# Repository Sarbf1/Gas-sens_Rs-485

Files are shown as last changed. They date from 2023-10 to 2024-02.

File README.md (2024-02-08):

# Gas-sens_Rs-485
a Compact, cheap gas sensor with RS-485 connectivity

## Concept:
24V supplied, Gas detector with half-duplex RS-485 interface. For industrial or home use and application ready product, containing a current or voltage output for reference measurment.
a sinlge LED used for showing cominucation or Error state. The small footprint makes it ready for most plastic enclosures.
the PCB can be hand-solderd with a bit of skill. 
Use cases can be in Garage systems (linked with the vents and gas alarm system), hobbyist workshop or any other room such as Office spaces and schools.

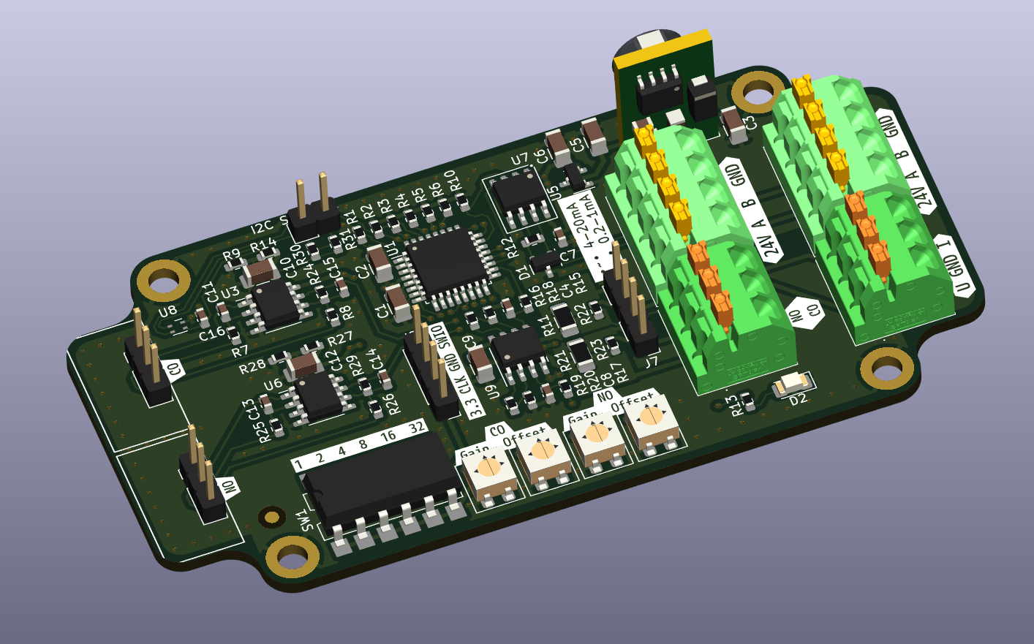
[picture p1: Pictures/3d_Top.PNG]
front-view

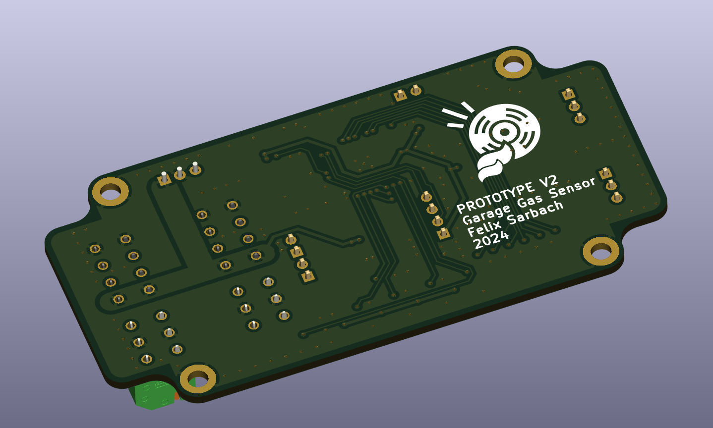
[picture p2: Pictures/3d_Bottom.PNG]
back-view


## Components

A STM32G031K8 is the logical unit. Is is cheap and readily available.
The very most components use standart fooprints. Thus, they are easily exchangeble in case of a shortage.
All parts are SMD, except for the Sensors, DCDC converter and Connectors.
All PCB components can be sourced by Mouser, except for the Gas Sensor.
For developement purposes (TAG v0.1) a gas sensor type MQ-X were used (MQ-7 and MQ-135)
TAG v0.2 makes use of the nemoto sensor, that uses low current and is more gas specific. 
The I2C conection gives a possibility, to further extend with more sensors, such as the Sensirion SHT4X.

## Programming
Hardware is developed in KiCad 7.0.

everything is programmed on STM Cube IDE. The Sensor and trim potentiometers are read-in using DMA.
The max and minimum values of the potentiometers can be set by the Modbus. the specific address are found in the excel-table "Modbus-memorymap" in the software folder.

## Simulation
Low pass filter for the PWM (from uC to OpAmp to voltag eand current output) has been simulated using LTSpice.

## next steps
- [X] PWM filter simulations
- [x] build and test prototype
- [x] Prgram IC for analog measurment and analog output
- [x] Find better sensor supplier and include it on second version PCB -> nemoto sensors
- [x] implement Modbus via RS-485
- [ ] create Bill of material
- [x] Make second physical prototype

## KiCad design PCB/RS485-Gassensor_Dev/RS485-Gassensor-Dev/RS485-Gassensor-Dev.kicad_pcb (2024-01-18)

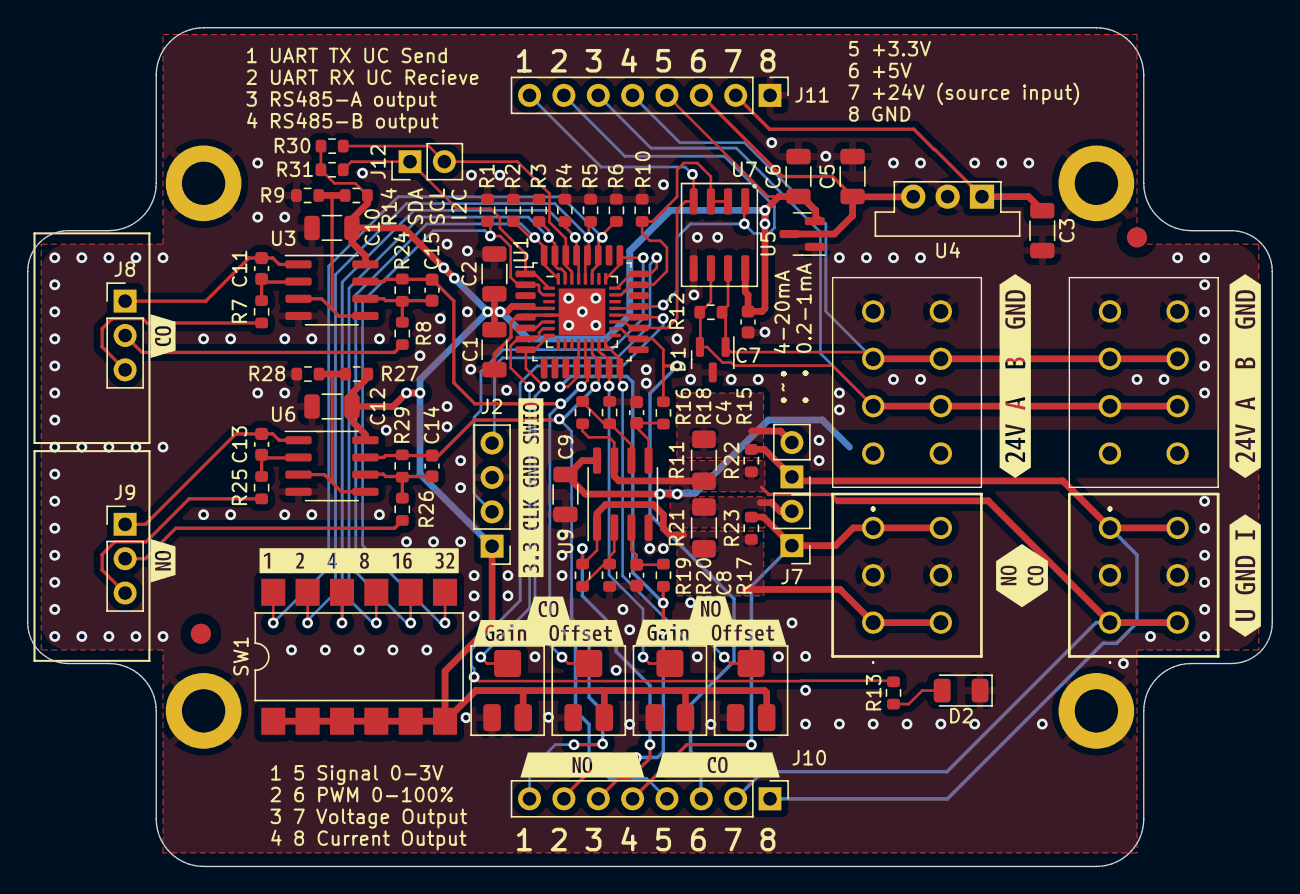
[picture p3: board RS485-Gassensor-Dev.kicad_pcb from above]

Board: 2 copper layers, 92.0 x 62.0 mm, 93 parts (0 on the bottom side), 52 nets.

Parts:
C1: CAP4.7uF; C_1206_3216Metric
C2: CAP100nF; C_1206_3216Metric
C3: CAP10uF; C_1206_3216Metric
C4, C8: 470nF; C_0603_1608Metric
C5: CAP22uF; C_1206_3216Metric
C6, C9, C10, C12: CAP1uF; C_1206_3216Metric
C7: CAP100nF; C_0603_1608Metric
C11, C13, C14, C15: CAP1uF; C_0603_1608Metric
D1: SM712_SOT23; SOT-23
D2: IR26-21C_L110_TR8; LED_1206_3216Metric
FID1, FID2: Fiducial; Fiducial_1.5mm_Mask3mm
H1, H2, H3, H4: MountingHole_Pad; MountingHole_3.2mm_M3_DIN965_Pad
J1, J3: Screw_Terminal_01x08; 1862068
J2: Screw_Terminal_01x04; PinHeader_1x04_P2.54mm_Vertical
J4, J5: Screw_Terminal_01x06; 1071000
J6, J7, J12: Conn_01x02_Pin; PinHeader_1x02_P2.54mm_Vertical
J8, J9: Conn_01x03; PinHeader_1x03_P2.54mm_Vertical
J10, J11: Conn_01x08; PinHeader_1x08_P2.54mm_Vertical
R1, R2, R3, R4, R5, R6, R7, R10, R24, R25, R29: R10K; R_0603_1608Metric
R8, R26: 10; R_0603_1608Metric
R9, R15, R17, R27, R28: 1k; R_0603_1608Metric
R11, R21: R470; R_1206_3216Metric_Pad1.30x1.75mm_HandSolder
R12: R220; R_0603_1608Metric
R13: R100; R_0603_1608Metric
R14, R16, R19: 2.2k; R_0603_1608Metric
R18, R20, R30, R31: R1K; R_0603_1608Metric
R22, R23: 10KR; R_0603_1608Metric
RV1, RV2, RV3, RV4: R_Poti_1K; Potentiometer_Bourns_3214J_Horizontal
SW1: SW_DIP_x06; SMDIP-12_W9.53mm
U1: STM32G031K8Tx; LQFP-32_7x7mm_P0.8mm
U2: STM32G031K8Ux; QFN-32-1EP_5x5mm_P0.5mm_EP3.45x3.45mm
U3, U6: MCP6002-xMS; SOIC-8_3.9x4.9mm_P1.27mm
U4: OKI-78SR-5_1.5-W36-C; Converter_DCDC_Murata_OKI-78SR_Vertical
U5: AP2127N-3.3; SOT-23
U7: LT1785xS8; SOIC-8_3.9x4.9mm_P1.27mm
U9: AD8676; SOIC-8_3.9x4.9mm_P1.27mm
kibuzzard-64E925B6: G***; kibuzzard-64E925B6
kibuzzard-64E958EB: G***; kibuzzard-64E958EB
kibuzzard-64E958FD: G***; kibuzzard-64E958FD
kibuzzard-64E92756: G***; kibuzzard-64E92756
kibuzzard-64ECCA5B: G***; kibuzzard-64ECCA5B
kibuzzard-64ECCA80: G***; kibuzzard-64ECCA80
kibuzzard-64ECCBAE: G***; kibuzzard-64ECCBAE
kibuzzard-651DD8EE: G***; kibuzzard-651DD8EE
kibuzzard-651DD908: G***; kibuzzard-651DD908
kibuzzard-655D1F2B: G***; kibuzzard-655D1F2B
kibuzzard-655D1F21: G***; kibuzzard-655D1F21
kibuzzard-650224BF: G***; kibuzzard-650224BF
kibuzzard-650224CC: G***; kibuzzard-650224CC
kibuzzard-650224F1: G***; kibuzzard-650224F1

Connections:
+3.3V: C1.1, C2.1, C6.1, C7.1, C10.1, C12.1, J2.1, J11.4, R14.2, R27.2, R30.1, R31.1, RV1.1, RV2.1, RV3.1, RV4.1, SW1.1, SW1.2, SW1.3, SW1.4, SW1.5, SW1.6, U1.4 (VDD), U2.4 (VDD), U3.8 (V+), U5.2 (VO), U6.8 (V+), U7.8 (VCC)
+5V: C5.1, J11.3, U4.3 (OUT), U5.3 (VI)
+24V: C3.1, C9.1, J1.1, J1.2, J3.1, J3.2, J11.2, U4.1 (IN), U9.8 (V+)
/Inputs and sensors/Counter_CO: C11.1, J8.1, U3.1
/Inputs and sensors/Counter_NO: C13.1, J9.1, U6.1
/Inputs and sensors/Reference_CO: J8.3, R7.1
/Inputs and sensors/Reference_NO: J9.3, R25.1
/Inputs and sensors/Working_CO: J8.2, R8.1
/Inputs and sensors/Working_NO: J9.2, R26.1
CO: C15.2, J10.4, R24.2, U1.13 (PA6), U2.13 (PA6), U3.7
DIP0: R1.1, SW1.7, U1.2 (PC14), U2.2 (PC14)
DIP1: R2.1, SW1.8, U1.32 (PB8), U2.32 (PB8)
DIP2: R3.1, SW1.9, U1.31 (PB7), U2.31 (PB7)
DIP3: R4.1, SW1.10, U1.29 (PB5), U2.29 (PB5)
DIP4: R5.1, SW1.11, U1.28 (PB4), U2.28 (PB4)
DIP5: R6.1, SW1.12, U1.27 (PB3), U2.27 (PB3)
GND: C1.2, C2.2, C3.2, C4.2, C5.2, C6.2, C7.2, C8.2, C9.2, C10.2, C12.2, D1.3 (common), D2.1 (K), H1.1, H2.1, H3.1, H4.1, J1.7, J1.8, J2.3, J3.7, J3.8, J4.3, J4.4, J5.3, J5.4, J11.1, R1.2, R2.2, R3.2, R4.2, R5.2, R6.2, R9.1, R10.2, R18.2, R20.2, R28.1, RV1.3, RV2.3, RV3.3, RV4.3, U1.5 (VSS), U2.5 (VSS), U2.33 (VSS), U3.4 (V-), U4.2 (GND), U5.1 (GND), U6.4 (V-), U7.5 (GND), U9.4 (V-)
Gain_CO: RV1.2, U1.7 (PA0), U2.7 (PA0)
Gain_NO: RV3.2, U1.15 (PB0), U2.15 (PB0)
I2C_SCL: J12.2, R30.2, U1.30 (PB6), U2.30 (PB6)
I2C_SDA: J12.1, R31.2, U1.1 (PB9), U2.1 (PB9)
I_Out_CO: J5.5, J5.6, J6.1, J10.1, R22.2
I_Out_NO: J4.5, J4.6, J7.1, J10.5, R23.2
LED: R13.2, U1.20 (PC6), U2.20 (PC6)
NO2: C14.2, J10.8, R29.2, U1.14 (PA7), U2.14 (PA7), U6.7
unnamed: D2.2 (A), R13.1
unnamed: J6.2, R11.2
unnamed: J7.2, R21.2
unnamed: R9.2, R14.1, U3.3 (+), U3.5 (+)
unnamed: C11.2, R7.2, U3.2 (-)
unnamed: C15.1, R8.2, R24.1, U3.6 (-)
unnamed: R27.1, R28.2, U6.3 (+), U6.5 (+)
unnamed: C13.2, R25.2, U6.2 (-)
unnamed: C14.1, R26.2, R29.1, U6.6 (-)
unnamed: C8.1, R17.2, U9.3 (+)
unnamed: R19.2, R20.1, U9.2 (-)
unnamed: C4.1, R15.2, U9.5 (+)
unnamed: R16.2, R18.1, U9.6 (-)
RS485-A: D1.2 (A2), J1.3, J1.4, J3.3, J3.4, J11.6, R12.1, U7.6 (A)
RS485-B: D1.1 (A1), J1.5, J1.6, J3.5, J3.6, J11.5, R12.2, U7.7 (B)
Read_!Enable: R10.1, U1.23 (PA12/PA10), U2.23 (PA12/PA10), U7.2 (~RE), U7.3 (DE)
SWCLK: J2.2, U1.25 (PA14), U2.25 (PA14)
SWDIO: J2.4, U1.24 (PA13), U2.24 (PA13)
T_NRST-Button: U1.6 (PF2), U2.6 (PF2)
UART_RX: J11.7, U1.21 (PA10/NC), U2.21 (PA10/NC), U7.1 (RO)
UART_TX: J11.8, U1.19 (PA9/NC), U2.19 (PA9/NC), U7.4 (DI)
U_Out_CO: J5.1, J5.2, J10.2, R11.1, R16.1, R22.1, U9.7
U_Out_NO: J4.1, J4.2, J10.6, R19.1, R21.1, R23.1, U9.1
analog_PWM_CO: J10.3, R15.1, U1.18 (PA8), U2.18 (PA8)
analog_PWM_NO: J10.7, R17.1, U1.12 (PA5), U2.12 (PA5)
offset_CO: RV2.2, U1.8 (PA1), U2.8 (PA1)
offset_NO: RV4.2, U1.16 (PB1), U2.16 (PB1)

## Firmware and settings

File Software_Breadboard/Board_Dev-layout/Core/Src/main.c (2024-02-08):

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
/* Includes ------------------------------------------------------------------*/
#include "main.h"
#include "adc.h"
#include "dma.h"
#include "i2c.h"
#include "tim.h"
#include "usart.h"
#include "gpio.h"

/* USER CODE BEGIN Includes */
#include <stdio.h>
#include <stdbool.h>
#include "modbusSlave.h"

/* USER CODE END Includes */


/* USER CODE BEGIN PV */

//UART_HandleTypeDef huart1;

struct sensor {
	uint32_t *input;
	uint32_t *gain;
	uint32_t *offset;
	uint32_t output;
};

uint8_t SLAVEID = 0;

/* USER CODE END PV */

void SystemClock_Config(void);
/* USER CODE BEGIN PFP */

//static void MX_GPIO_Init(void);
//static void MX_USART1_UART_Init(void);


/* USER CODE END PFP */

/* USER CODE BEGIN 0 */

uint32_t value_adc_DMA[7]={0,0,0,0,0,0,0};  // #TODO restructure as struct instrad array
int32_t y = 0;
int32_t a = 1;
int32_t x = 1;
int32_t b = 0;

uint8_t RxData[256];
uint8_t TxData[256];


void HAL_UARTEx_RxEventCallback(UART_HandleTypeDef *huart, uint16_t Size)
{
	if (RxData[0] == SLAVEID)
	{
		switch (RxData[1]){
		case 0x03:
			readHoldingRegs();
			break;
		case 0x04:
			readInputRegs();
			break;
		case 0x01:
			readCoils();
			break;
		case 0x02:
			readInputs();
			break;
		case 0x06:
			writeSingleReg();
			break;
		case 0x10:
			writeHoldingRegs();
			break;
		case 0x05:
			writeSingleCoil();
			break;
		case 0x0F:
			writeMultiCoils();
			break;
		default:
			modbusException(ILLEGAL_FUNCTION);
			break;
		}
	}

	HAL_UARTEx_ReceiveToIdle_IT(&huart1, RxData, 256);
}



/* USER CODE END 0 */

/**
  * @brief  The application entry point.
  * @retval int
  */
int main(void)
{
  /* MCU Configuration--------------------------------------------------------*/

  /* Reset of all peripherals, Initializes the Flash interface and the Systick. */
  HAL_Init();

  /* Configure the system clock */
  SystemClock_Config();

  /* Initialize all configured peripherals */
  MX_GPIO_Init();
  MX_DMA_Init();
  MX_ADC1_Init();
  MX_TIM1_Init();
  MX_USART1_UART_Init();
  MX_TIM2_Init();
  MX_I2C1_Init();
  /* USER CODE BEGIN 2 */


	char port0 = HAL_GPIO_ReadPin(GPIO_IN_DIP0_GPIO_Port, GPIO_IN_DIP0_Pin);
	char port1 = HAL_GPIO_ReadPin(GPIO_IN_DIP1_GPIO_Port, GPIO_IN_DIP1_Pin);
	char port2 = HAL_GPIO_ReadPin(GPIO_IN_DIP2_GPIO_Port, GPIO_IN_DIP2_Pin);
	char port3 = HAL_GPIO_ReadPin(GPIO_IN_DIP3_GPIO_Port, GPIO_IN_DIP3_Pin);
	char port4 = HAL_GPIO_ReadPin(GPIO_IN_DIP4_GPIO_Port, GPIO_IN_DIP4_Pin);
	char port5 = HAL_GPIO_ReadPin(GPIO_IN_DIP5_GPIO_Port, GPIO_IN_DIP5_Pin);

	SLAVEID = (port0 << 5) | (port1 << 4) | (port2 << 3) | (port3 << 2) | (port4 << 1) |  port5 ;

  HAL_UARTEx_ReceiveToIdle_IT(&huart1, RxData, 256);

	struct sensor Co, No, Temp;

	Co.input = &value_adc_DMA[0];
	No.input = &value_adc_DMA[1];
	Co.gain = &value_adc_DMA[2];
	Co.offset = &value_adc_DMA[3];
	No.gain = &value_adc_DMA[4];
	No.offset = &value_adc_DMA[5];
	Temp.input = &value_adc_DMA[6];
	Temp.gain = 1; //#TODO get this value from internal saved reference value
	Temp.offset = 0;



	HAL_TIM_PWM_Start(&htim1, TIM_CHANNEL_1); //start output PWM 1 CO
	HAL_TIM_PWM_Start(&htim2, TIM_CHANNEL_1); //start output PWM 2 NO
	TIM1->CCR1 =1;
	TIM1->CCR2 =1;
	HAL_ADC_Start_DMA(&hadc1, value_adc_DMA, 7); //aquire date from all ADC

  /* USER CODE END 2 */

  /* Infinite loop */
  /* USER CODE BEGIN WHILE */
	while (1)
	{
    /* USER CODE END WHILE */

    /* USER CODE BEGIN 3 */

		HAL_ADC_Start_DMA(&hadc1, value_adc_DMA, 7); //this step takes ca 50uS #TODO perhaps export to internal timer callback (trigger)


		x= TIM1->ARR* *Co.input/4095;
		a= *Co.gain*(Input_Registers_Database[13]-Input_Registers_Database[11])/4095+Input_Registers_Database[11]; // initial pitch between 20 and 180 [in percent]
		b= *Co.offset*(Input_Registers_Database[16]-Input_Registers_Database[14])/4095 + Input_Registers_Database[14]; //results between -409 and +409
		y=a*x*0.01+b*0.1;
		if (y<0) {y=0;}
		if (y>TIM1->ARR) {y=TIM1->ARR;}

		TIM1->CCR1 =y ;

		x= (TIM2->ARR* *No.input)/4095;
		a= *No.gain*(Input_Registers_Database[23]-Input_Registers_Database[21])/4095+Input_Registers_Database[21];
		b= *No.offset*(Input_Registers_Database[26]-Input_Registers_Database[24])/4095 + Input_Registers_Database[24];
		y=a*x*0.01+b*0.1;
		if (y<0) {y=0;}
		if (y>TIM2->ARR) {y=TIM2->ARR;}

		TIM2->CCR1 = y;


		Input_Registers_Database[10]=*Co.input;
		Input_Registers_Database[12]=*Co.gain;
		Input_Registers_Database[15]=*Co.offset;
		Input_Registers_Database[17]=TIM1->CCR1;

		Input_Registers_Database[20]=*Co.input;
		Input_Registers_Database[22]=*Co.gain;
		Input_Registers_Database[25]=*Co.offset;
		Input_Registers_Database[27]=TIM2->CCR1;

		//Input_Registers_Database[37]=Temp;

		HAL_GPIO_TogglePin(GPIOC, GPIO_PIN_6); //toggle LED to measure cycle time
	}
  /* USER CODE END 3 */
}

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


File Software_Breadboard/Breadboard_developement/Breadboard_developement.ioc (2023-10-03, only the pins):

Mcu.UserName=STM32G031K8Tx
PA0.GPIO_Label=ADC1_IN0_GAIN_CO
PA0.Signal=ADC1_IN0
PA1.GPIO_Label=ADC1_IN1_OFFSET_CO
PA1.Signal=ADC1_IN1
PA10.Signal=USART1_RX
PA13.GPIO_Label=T_JTMS
PA13.Signal=SYS_SWDIO
PA14-BOOT0.GPIO_Label=T_JTCK
PA14-BOOT0.Signal=SYS_SWCLK
PA2.GPIO_Label=T_VCP_TX
PA2.Signal=USART2_TX
PA3.GPIO_Label=T_VCP_RX
PA3.Signal=USART2_RX
PA5.GPIO_Label=TIM2_CH1_PWM_NO
PA5.Signal=S_TIM2_CH1_ETR
PA6.GPIO_Label=ADC1_IN6_CO
PA6.Signal=ADC1_IN6
PA7.GPIO_Label=ADC1_IN7_NO
PA7.Signal=ADC1_IN7
PA8.GPIO_Label=TIM1_CH1_PWM_CO
PA8.Signal=S_TIM1_CH1
PA9.Signal=USART1_TX
PB0.GPIO_Label=ADC1_IN8_GAIN_NO
PB0.Signal=ADC1_IN8
PB1.GPIO_Label=ADC1_IN9_OFFSET_NO
PB1.Signal=ADC1_IN9
PB3.GPIO_Label=GPIO_IN_DIP5
PB3.Signal=GPIO_Input
PB4.GPIO_Label=GPIO_IN_DIP4
PB4.Signal=GPIO_Input
PB5.GPIO_Label=GPIO_IN_DIP3
PB5.Signal=GPIO_Input
PB6.GPIO_Label=GPIO_IN_DIP2
PB6.Signal=GPIO_Input
PB7.GPIO_Label=GPIO_IN_DIP1
PB7.Signal=GPIO_Input
PB8.GPIO_Label=GPIO_IN_DIP0
PB8.Signal=GPIO_Input
PC6.GPIO_Label=LD3 [Green]
PC6.Signal=GPIO_Output

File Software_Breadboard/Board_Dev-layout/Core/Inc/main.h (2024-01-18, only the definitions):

#define GPIO_IN_DIP0_Pin GPIO_PIN_14
#define GPIO_IN_DIP0_GPIO_Port GPIOC
#define ADC1_IN0_GAIN_CO_Pin GPIO_PIN_0
#define ADC1_IN0_GAIN_CO_GPIO_Port GPIOA
#define ADC1_IN1_OFFSET_CO_Pin GPIO_PIN_1
#define ADC1_IN1_OFFSET_CO_GPIO_Port GPIOA
#define TIM2_CH1_PWM_NO_Pin GPIO_PIN_5
#define TIM2_CH1_PWM_NO_GPIO_Port GPIOA
#define ADC1_IN6_CO_Pin GPIO_PIN_6
#define ADC1_IN6_CO_GPIO_Port GPIOA
#define ADC1_IN7_NO_Pin GPIO_PIN_7
#define ADC1_IN7_NO_GPIO_Port GPIOA
#define ADC1_IN8_GAIN_NO_Pin GPIO_PIN_0
#define ADC1_IN8_GAIN_NO_GPIO_Port GPIOB
#define ADC1_IN9_OFFSET_NO_Pin GPIO_PIN_1
#define ADC1_IN9_OFFSET_NO_GPIO_Port GPIOB
#define TIM1_CH1_PWM_CO_Pin GPIO_PIN_8
#define TIM1_CH1_PWM_CO_GPIO_Port GPIOA
#define LD3_Pin GPIO_PIN_6
#define LD3_GPIO_Port GPIOC
#define T_JTMS_Pin GPIO_PIN_13
#define T_JTMS_GPIO_Port GPIOA
#define T_JTCK_Pin GPIO_PIN_14
#define T_JTCK_GPIO_Port GPIOA
#define GPIO_IN_DIP5_Pin GPIO_PIN_3
#define GPIO_IN_DIP5_GPIO_Port GPIOB
#define GPIO_IN_DIP4_Pin GPIO_PIN_4
#define GPIO_IN_DIP4_GPIO_Port GPIOB
#define GPIO_IN_DIP3_Pin GPIO_PIN_5
#define GPIO_IN_DIP3_GPIO_Port GPIOB
#define GPIO_IN_DIP2_Pin GPIO_PIN_7
#define GPIO_IN_DIP2_GPIO_Port GPIOB
#define GPIO_IN_DIP1_Pin GPIO_PIN_8
#define GPIO_IN_DIP1_GPIO_Port GPIOB

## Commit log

2023-07-04 Create .gitignore
    added gitignore for C, windows, Kicad
2023-07-04 added PCB
    added Kicad PCB
    [RS485-Gassensor.kicad_pcb, RS485-Gassensor.kicad_sch]
2023-07-04 Update README.md
    added current status and todo
2023-07-06 clean up, minor extension
    cleaned up /reorganized scematic,
    added optional termination resistor for RS-485
    [RS485-Gassensor.kicad_pcb, RS485-Gassensor.kicad_sch]
2023-08-20 restarted Project.
    new PCB, improved component chioce
    strarted program with STM32 IDE
    [RS485-Gassensor.kicad_pcb, RS485-Gassensor.kicad_sch]
2023-08-27 new PCB
    new PCB, working DMA
    [RS485-Gassensor.kicad_pcb, RS485-Gassensor.kicad_sch]
2023-10-03 imoproved filter
    one dual channel Op amp, corrections from first produced prototype
    [Barod_Prototype Debug.cfg, Breadboard_developement Debug.cfg, Power_Connectors.kicad_sch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]
2023-10-25 added Modbus / RS485
    [RS485-Gassensor.kicad_pcb, RS485-Gassensor.kicad_sch, Sensor_Inputs.kicad_sch]
2024-01-18 made For NAP505 and NAP550
    [Board_Dev-layout Debug.cfg, Power_Connectors.kicad_sch, RS485-Gassensor-Dev.kicad_pcb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]
2024-02-08 code and hardware imrovement V2
    added I2C, and modbus functionailties
    [Barod_Prototype Debug.cfg, Modbus_memorymap.xlsx, output.kicad_sch]

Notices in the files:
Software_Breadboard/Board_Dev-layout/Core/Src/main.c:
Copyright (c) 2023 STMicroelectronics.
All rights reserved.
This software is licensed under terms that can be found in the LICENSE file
